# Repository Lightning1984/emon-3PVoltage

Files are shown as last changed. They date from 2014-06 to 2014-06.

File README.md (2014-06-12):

emon-3PVoltage
==============

Open Energy Monitoring 3 Phase Voltage Sensing Hardware with optoisolated I²C Interface

Images of the finished device can be found here:
<table style="width:194px;"><tr><td align="center" style="height:194px;background:url(https://www.gstatic.com/pwa/s/v/lighthousefe_241.01/transparent_album_background.gif) no-repeat left"></td></tr><tr><td style="text-align:center;font-family:arial,sans-serif;font-size:11px"><a href="https://picasaweb.google.com/rdobroun/Emon3PVoltage?authuser=0&feat=embedwebsite" style="color:#4D4D4D;font-weight:bold;text-decoration:none;">Emon3PVoltage</a></td></tr></table>

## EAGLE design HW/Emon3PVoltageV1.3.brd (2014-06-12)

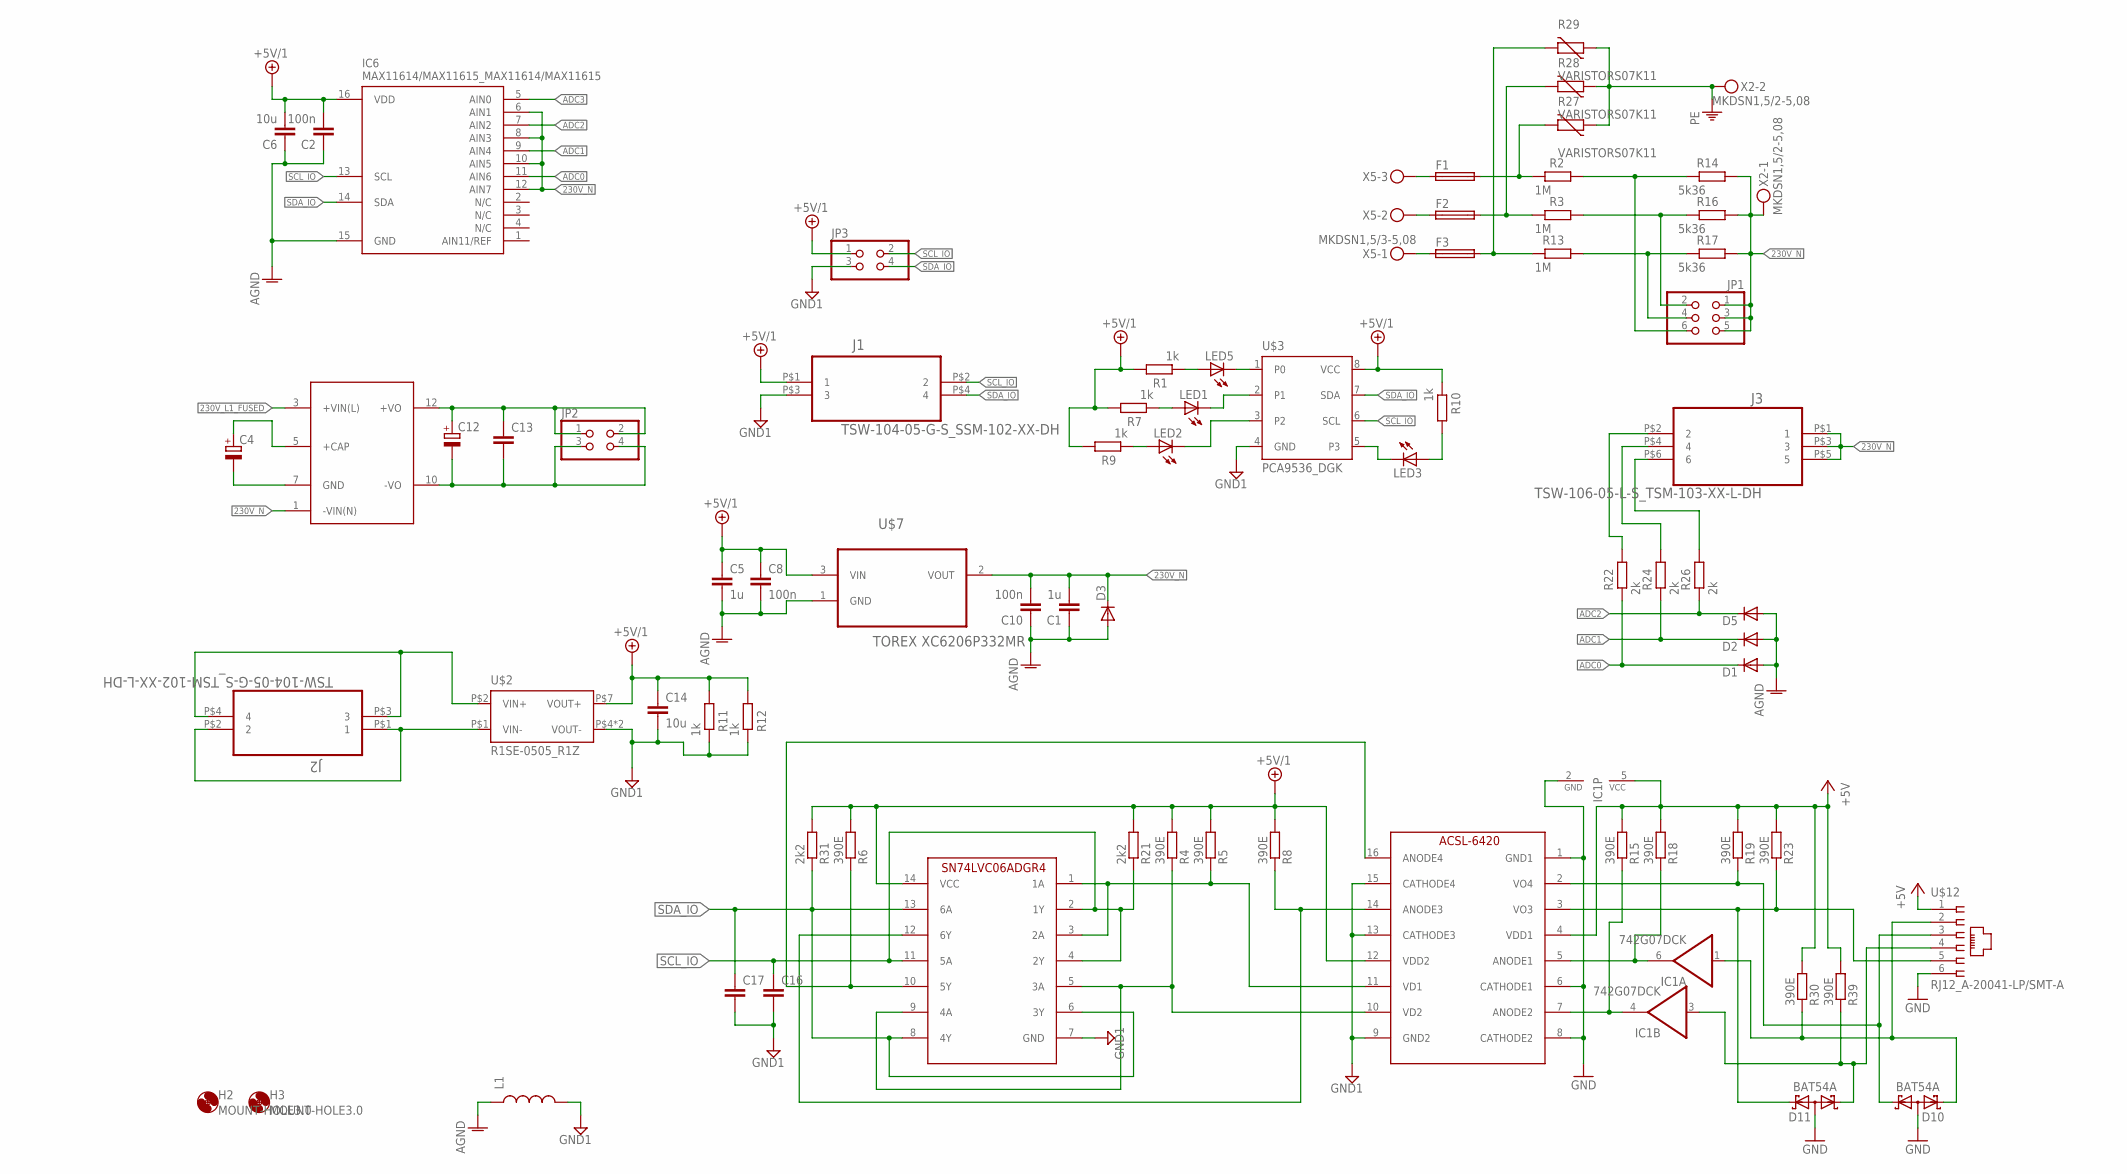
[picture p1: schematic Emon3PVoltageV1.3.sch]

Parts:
C1, C5: 1u; C0805
C2, C8, C10: 100n; C0805
C4: CPOL-EUE5-13; E5-13
C6, C14: 10u; C0805
C12: CPOL-EUE5-10.5; E5-10,5
C13, C16, C17: C-EUC0805; C0805
D1, D2, D3, D5: DIODE-SOD523; SOD523
D10, D11: BAT54A; SOT23
F1, F2, F3: TE5
H2, H3: MOUNT-HOLE3.0; 3,0
IC1: 742G07DCK; SC70-6
IC6: MAX11614/MAX11615_MAX11614/MAX11615; QSOP16_2
J1: TSW-104-05-G-S_SSM-102-XX-DH; SAMTEC_SSM-102-XX-DH
J2: TSW-104-05-G-S_TSM-102-XX-L-DH; SAMTEC_TSM-102-XX-L-DH
J3: TSW-106-05-L-S_TSM-103-XX-L-DH; SAMTEC_TSM-103-XX-L-DH
JP1: PINHD-2X3; 2X03
JP2, JP3: PINHD-2X2; 2X02
L1: INDUCTOR0805; 0805
LED1, LED2, LED3, LED5: LEDCHIPLED_1206; CHIPLED_1206
R1, R7, R9, R10, R11, R12: 1k; R1206
R2, R3, R13: 1M; 0207/12
R4, R5, R6, R8, R15, R18, R19, R23, R30, R39: 390E; R1206
R14, R16, R17: 5k36; R1206
R21, R31: 2k2; R1206
R22, R24, R26: 2k; R1206
R27, R28, R29: VARISTORS07K11; S07K11
U$1: LS03-15BXXSR2; LS03
U$2: R1SE-0505_R1Z; R1Z
U$3: PCA9536_DGK; DGK_S-PDSO-G8
U$7: TOREX XC6206P332MR; SOT95P237X112-3N
U$10: ACSL-6420; SO16
U$11: SN74LVC06ADRG4; SO-14
U$12: RJ12_A-20041-LP/SMT-A; A-2004-1-LP-SMT-B
X2: MKDSN1,5/2-5,08
X5: MKDSN1,5/3-5,08

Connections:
230V_L1_FUSED: F1.2, R2.2, R27.2, U$1.3 (+VIN(L))
230V_N: C1.2, C10.2, D3.C, IC6.6 (AIN1), IC6.8 (AIN3), IC6.10 (AIN5), IC6.12 (AIN7), J3.P$1 (1), J3.P$3 (3), J3.P$5 (5), JP1.1, JP1.3, JP1.5, R14.1, R16.1, R17.1, U$1.1 (-VIN(N)), U$7.2 (VOUT), X2.1
+5V: IC1.5 (VCC), R15.2, R18.2, R19.2, R23.2, R30.2, R39.2, U$10.4 (VDD1), U$12.1
+5V/1: C2.2, C5.1, C6.2, C8.1, C14.1, IC6.16 (VDD), J1.P$1 (1), JP3.1, R1.1, R4.2, R5.2, R6.2, R7.1, R8.2, R9.1, R10.2, R11.1, R12.1, R21.2, R31.2, U$2.P$7 (VOUT+), U$3.8 (VCC), U$7.3 (VIN), U$10.12 (VDD2), U$11.14 (VCC)
ADC0: D1.C, IC6.11 (AIN6), R22.2
ADC1: D2.C, IC6.9 (AIN4), R24.2
ADC2: D5.C, IC6.7 (AIN2), R26.2
ADC3: IC6.5 (AIN0)
AGND: C1.1, C2.1, C5.2, C6.1, C8.2, C10.1, D1.A, D2.A, D3.A, D5.A, IC6.15 (GND), L1.1, U$7.1 (GND)
GND: D10.3 (AA), D11.3 (AA), IC1.2 (GND), U$10.1 (GND1), U$10.6 (CATHODE1), U$10.8 (CATHODE2), U$12.6
GND1: C14.2, C16.2, C17.2, J1.P$3 (3), JP3.3, L1.2, R11.2, R12.2, U$2.P$4 (VOUT-), U$2.P$5 (VOUT-), U$3.4 (GND), U$10.9 (GND2), U$10.13 (CATHODE3), U$10.15 (CATHODE4), U$11.7 (GND)
unnamed: IC1.6 (O), R18.1, U$10.5 (ANODE1)
unnamed: LED3.C, U$3.5 (P3)
unnamed: C4.+, U$1.5 (+CAP)
unnamed: J3.P$2 (2), R22.1
unnamed: LED5.A, R1.2
unnamed: LED2.A, R9.2
unnamed: LED1.A, R7.2
unnamed: R5.1, U$10.11 (VD1), U$11.1 (1A), U$11.3 (2A)
unnamed: F2.2, R3.2, R28.2
unnamed: IC1.4 (O), R15.1, U$10.7 (ANODE2)
unnamed: F3.2, R13.2, R29.2
unnamed: J2.P$3 (3), J2.P$4 (4), U$2.P$2 (VIN+)
unnamed: JP1.2, R3.1, R16.2
unnamed: J2.P$1 (1), J2.P$2 (2), U$2.P$1 (VIN-)
unnamed: F3.1, X5.1
unnamed: R4.1, U$10.10 (VD2), U$11.5 (3A), U$11.9 (4A)
unnamed: F2.1, X5.2
unnamed: F1.1, X5.3
unnamed: C4.-, U$1.7 (GND)
unnamed: J3.P$6 (6), R26.1
unnamed: C12.-, C13.2, JP2.3, JP2.4, U$1.10 (-VO)
unnamed: C12.+, C13.1, JP2.1, JP2.2, U$1.12 (+VO)
unnamed: J3.P$4 (4), R24.1
unnamed: LED5.C, U$3.1 (P0)
unnamed: JP1.4, R13.1, R17.2
unnamed: LED1.C, U$3.2 (P1)
unnamed: R6.1, U$10.16 (ANODE4), U$11.10 (5Y)
unnamed: R8.1, U$10.14 (ANODE3), U$11.12 (6Y)
unnamed: JP1.6, R2.1, R14.2
unnamed: LED2.C, U$3.3 (P2)
unnamed: LED3.A, R10.1
PE: R27.1, R28.1, R29.1, X2.2
SCL_IO: C16.1, IC6.13 (SCL), J1.P$2 (2), JP3.2, R21.1, U$3.6 (SCL), U$11.2 (1Y), U$11.4 (2Y), U$11.11 (5A)
SCL_RX_UC: D10.1 (K1), R19.1, U$10.2 (VO4), U$12.3
SCL_TX_UC: D10.2 (K2), IC1.1 (I), R30.1, U$12.2
SDA_IO: C17.1, IC6.14 (SDA), J1.P$4 (4), JP3.4, R31.1, U$3.7 (SDA), U$11.6 (3Y), U$11.8 (4Y), U$11.13 (6A)
SDA_RY_UC: D11.2 (K2), R23.1, U$10.3 (VO3), U$12.5
SDA_TY_UC: D11.1 (K1), IC1.3 (I), R39.1, U$12.4

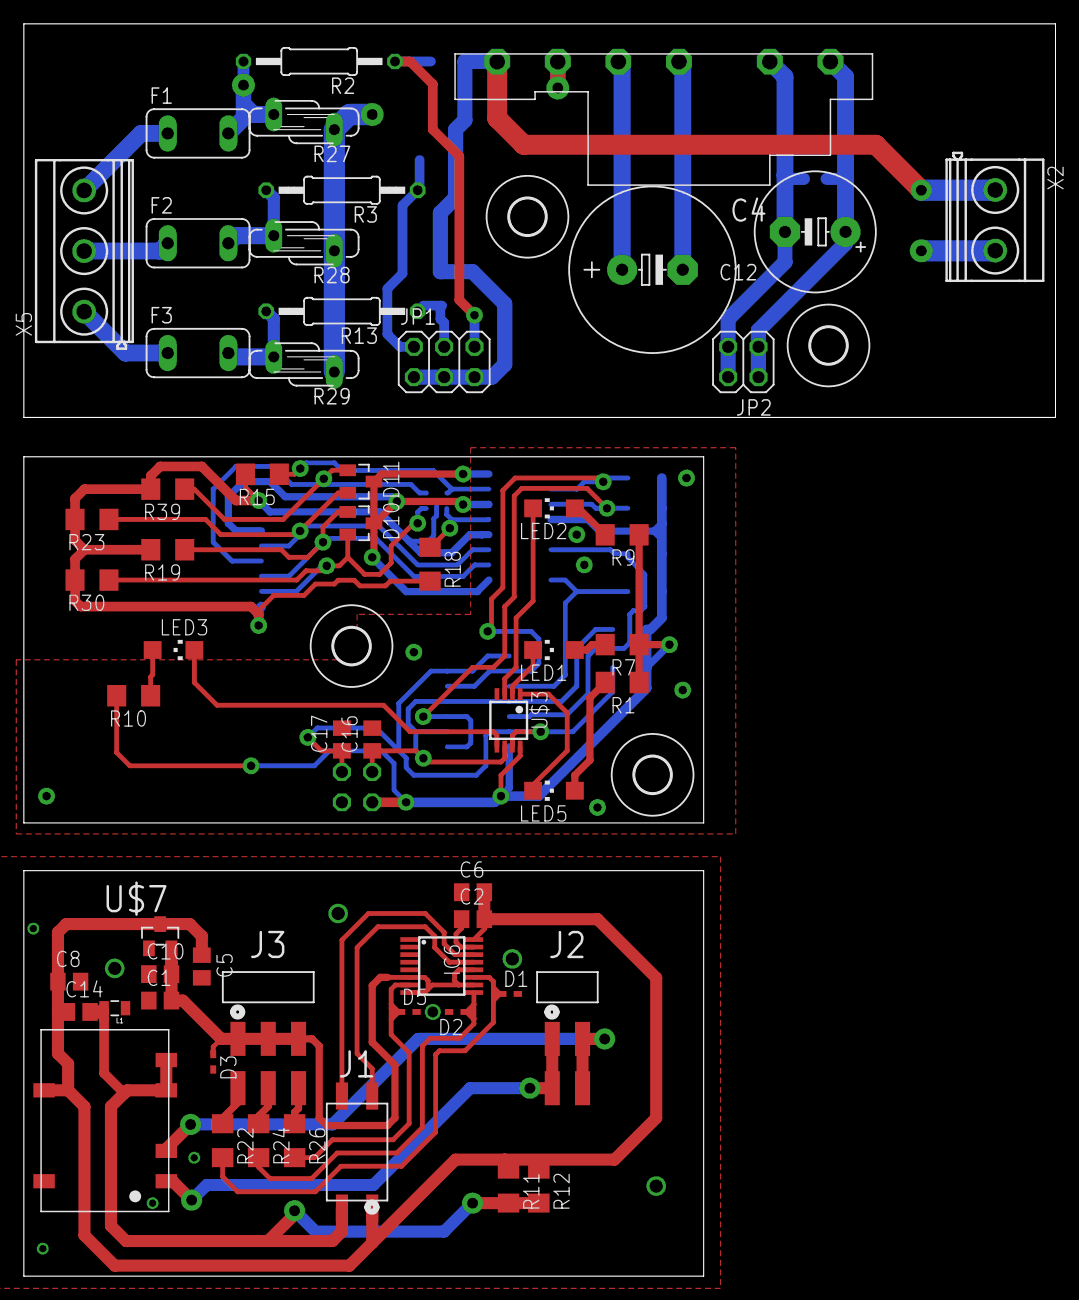
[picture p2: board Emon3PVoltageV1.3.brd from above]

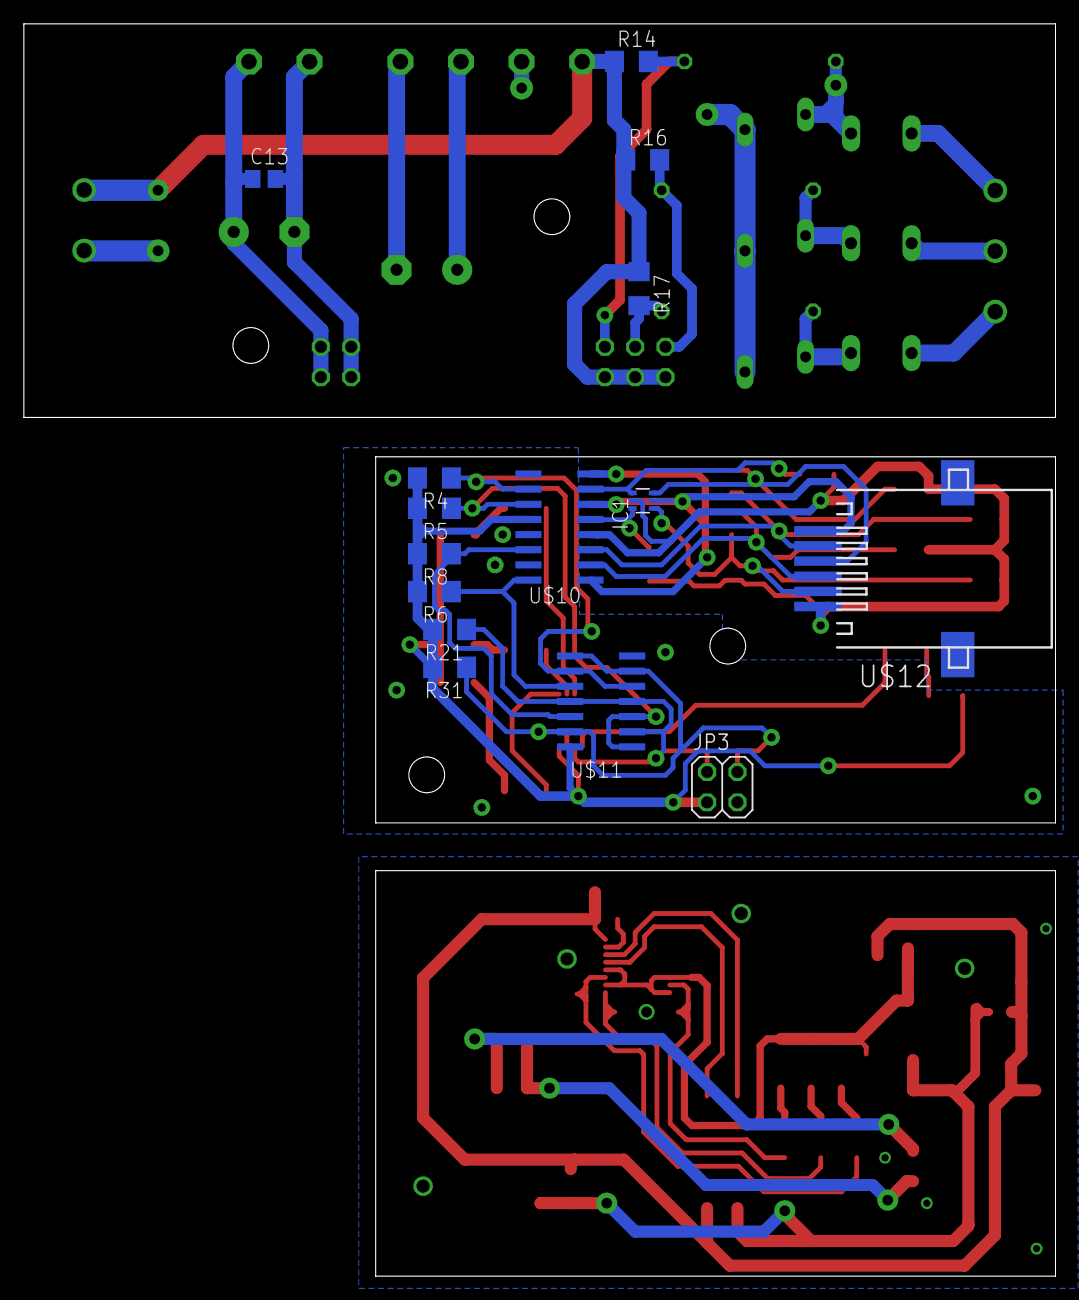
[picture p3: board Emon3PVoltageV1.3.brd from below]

Board: 2 copper layers, 86.5 x 105.0 mm, 77 parts (15 on the bottom side), 48 nets.

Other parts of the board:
H1, H4: MOUNT-HOLE3.0; 3,0

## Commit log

2014-06-12 added brd and schematic files
    [Emon3PVoltageV1.3.brd, Emon3PVoltageV1.3.sch]
2014-06-12 Added voltage divider calculation
    [VoltageDivider.xlsx]
2014-06-12 Update README.md
    Images of the finished device can be seen under:

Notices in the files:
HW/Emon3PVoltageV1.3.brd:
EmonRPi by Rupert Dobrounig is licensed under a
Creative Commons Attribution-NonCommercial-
